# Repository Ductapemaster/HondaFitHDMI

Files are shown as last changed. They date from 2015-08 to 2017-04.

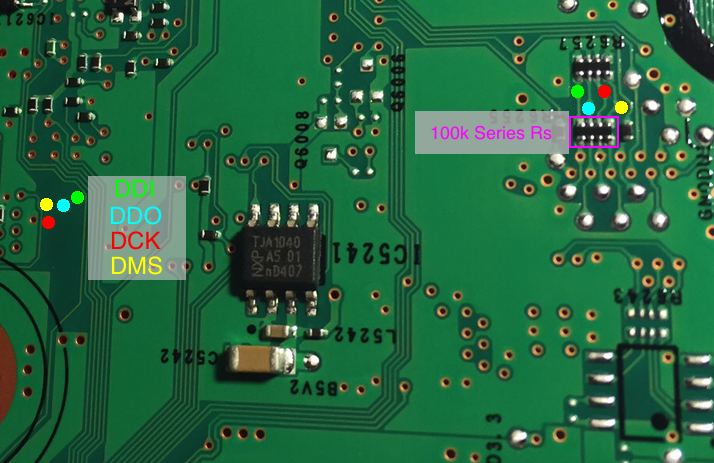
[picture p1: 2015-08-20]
wiki/hu_internals/annotated/v850_debug_signals.png

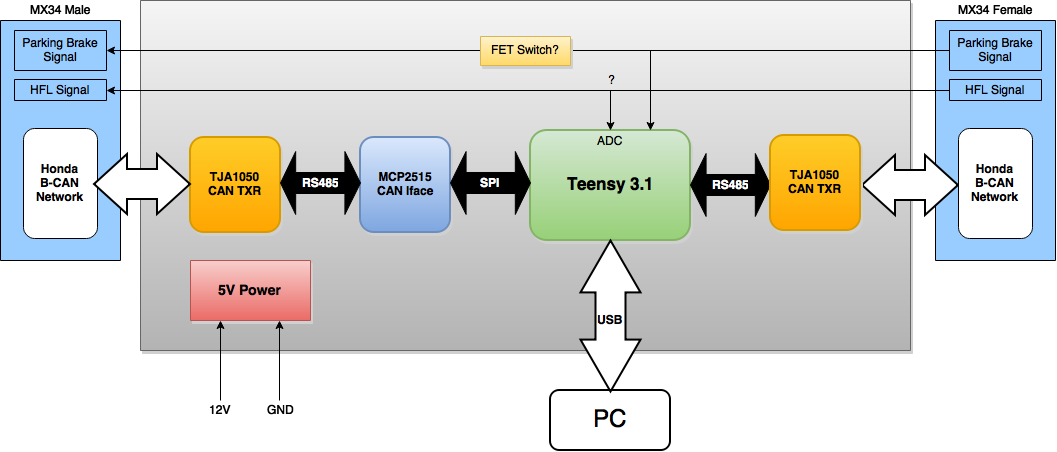
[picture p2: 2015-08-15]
wiki/images/block_diagram.png

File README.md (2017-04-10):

# HondaFitHDMI
Various efforts into hacking the 2015 Honda Fit head unit to allow HDMI input and disable other lockouts while driving

A demonstration of the prototype hardware can be found here: http://youtu.be/ffWo1LNsV7A

Please see the Wiki for the most updated information!

## Contents
**./can_analysis**: Captured data from CAN bus.  Analysis spreadsheet showing various IDs and their functions

**./proof_of_concept**: Files relating to the proof of concept hardware and software

**./teensy**: Firmware and related information for teensy-based prototype hardware

**./wiki**: Wiki content

# Git-iquette
Please forgive my tresspasses on the typical Git workflow.  This is my first solo git-tracked project and I'm learning as I go along!

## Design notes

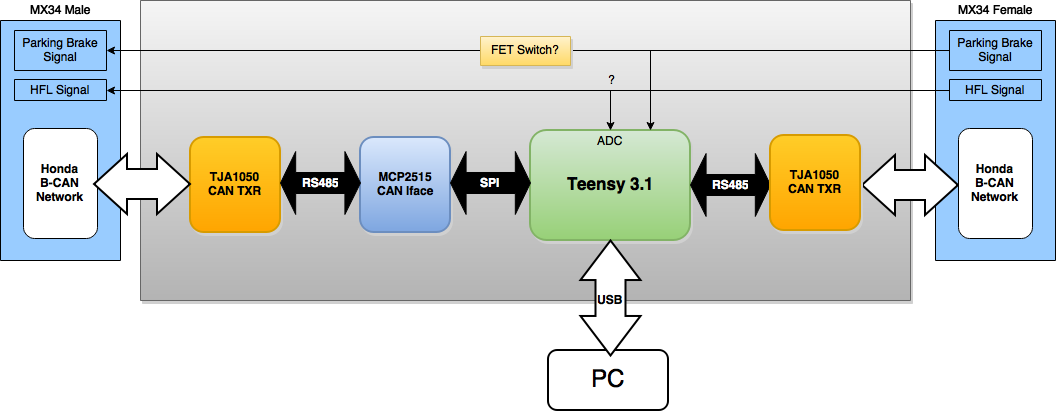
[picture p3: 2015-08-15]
wiki/images/proto_block_diagram.png

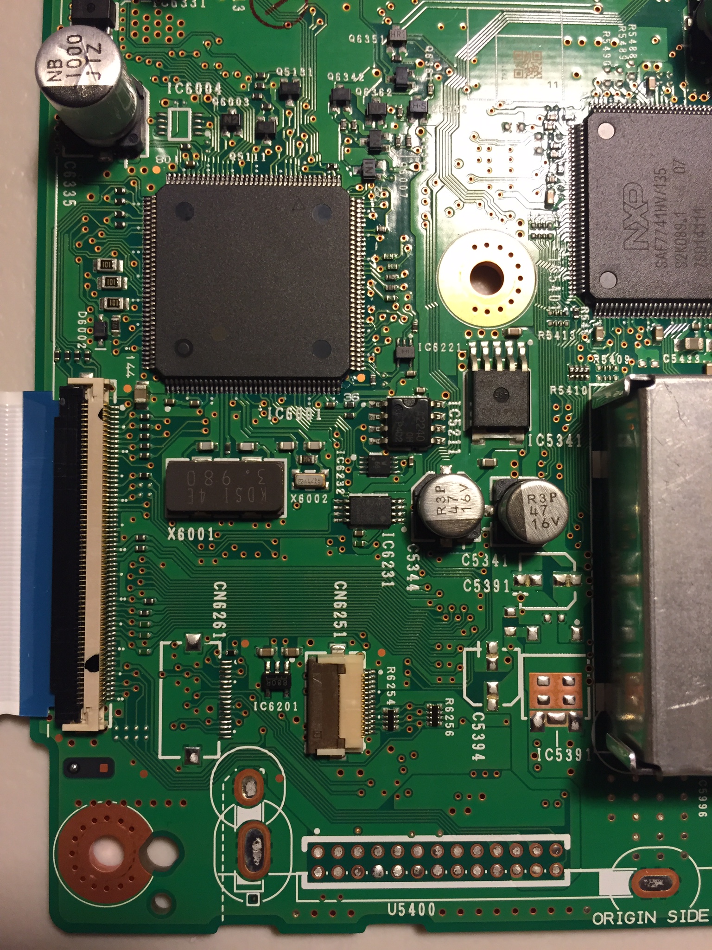
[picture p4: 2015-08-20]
wiki/hu_internals/original/pcb_audio_v850detail.JPG

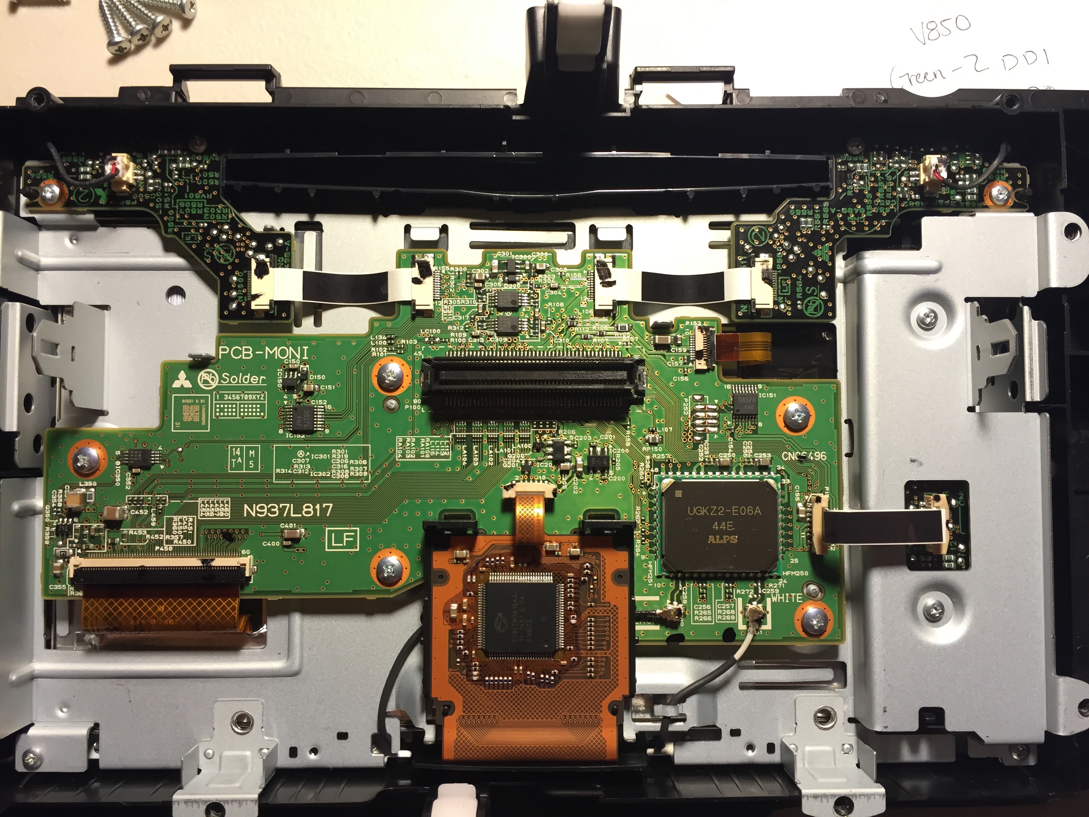
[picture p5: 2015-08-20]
wiki/hu_internals/original/pcb_display_bottom.jpg

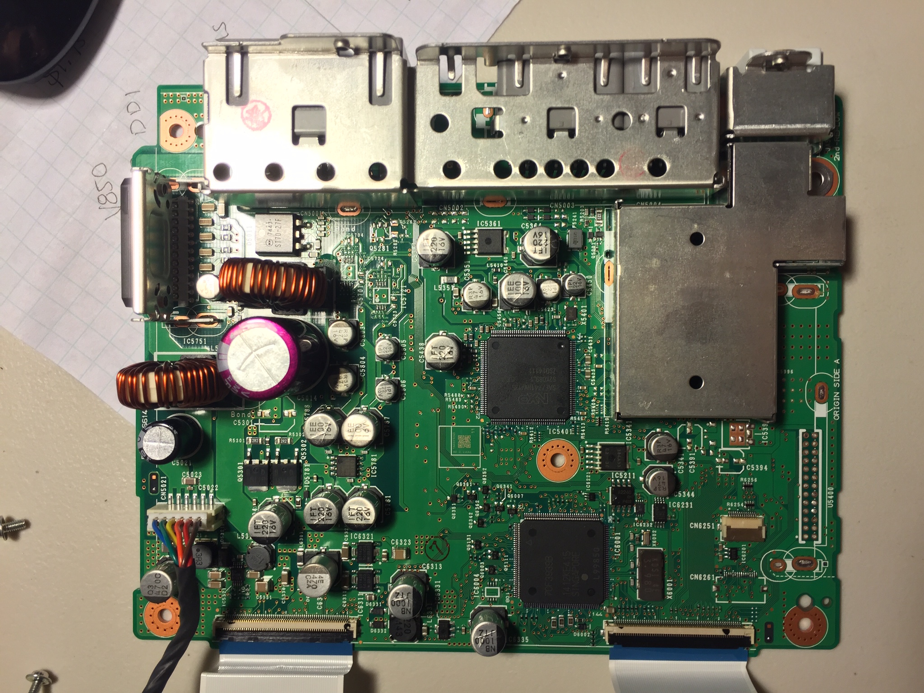
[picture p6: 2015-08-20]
wiki/hu_internals/original/pcb_audio_top.JPG

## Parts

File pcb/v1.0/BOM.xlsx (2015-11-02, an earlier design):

Part | Value | Device | Package | Description | MF | MPN | Digikey
C1 |  | C-EUC0603 | C0603 | CAPACITOR, European symbol |  |  | 478-6211-2-ND
C2 |  | C-EUC0603 | C0603 | CAPACITOR, European symbol |  |  | 478-6211-2-ND
C3 | 100n | C-EUC0603 | C0603 | CAPACITOR, European symbol |  |  | 311-1088-1-ND
D1 |  | LEDCHIP-LED0805 | CHIP-LED0805 | LED |  |  | 160-1423-1-ND
D2 |  | LEDCHIP-LED0805 | CHIP-LED0805 | LED |  |  | 160-1423-1-ND
Q1 | 10MHz | CRYSTALHC49S | HC49/S | CRYSTAL |  |  | 887-2008-ND
R1 | 120R | R-US_R0805 | R0805 | RESISTOR, American symbol |  |  | 311-120ARCT-ND
R2 | 120R | R-US_R0805 | R0805 | RESISTOR, American symbol |  |  | 311-120ARCT-ND
R3 | 120R | R-US_R0805 | R0805 | RESISTOR, American symbol |  |  | 311-120ARCT-ND
R4 | 120R | R-US_R0805 | R0805 | RESISTOR, American symbol |  |  | 311-120ARCT-ND
U1 | TEENSY_3.1_BASIC | TEENSY_3.1_BASIC | TEENSY_3.1_BASIC | Footprint for Teensy 3.1 board using all pin connections on the outer perimeter |  |  | 929974E-01-14-ND
U2 | MCP2515TSOP | MCP2515TSOP | TSSOP20 | MCP2515 Standalone CAN-Controller |  |  | MCP2515T-I/STCT-ND
U3 | TJA1050 | TJA1050 | SO08 | High speed CAN transceiver |  |  | 568-10292-1-ND
U4 | TJA1050 | TJA1050 | SO08 | High speed CAN transceiver |  |  | 568-10292-1-ND
X1 | CON_10X2F_JAE_MX34020NF1 | CON_10X2F_JAE_MX34020NF1 | CON_10X2_JAE_MX34020NF1 | JAE MX34 Series Connector, 10x2 Rows

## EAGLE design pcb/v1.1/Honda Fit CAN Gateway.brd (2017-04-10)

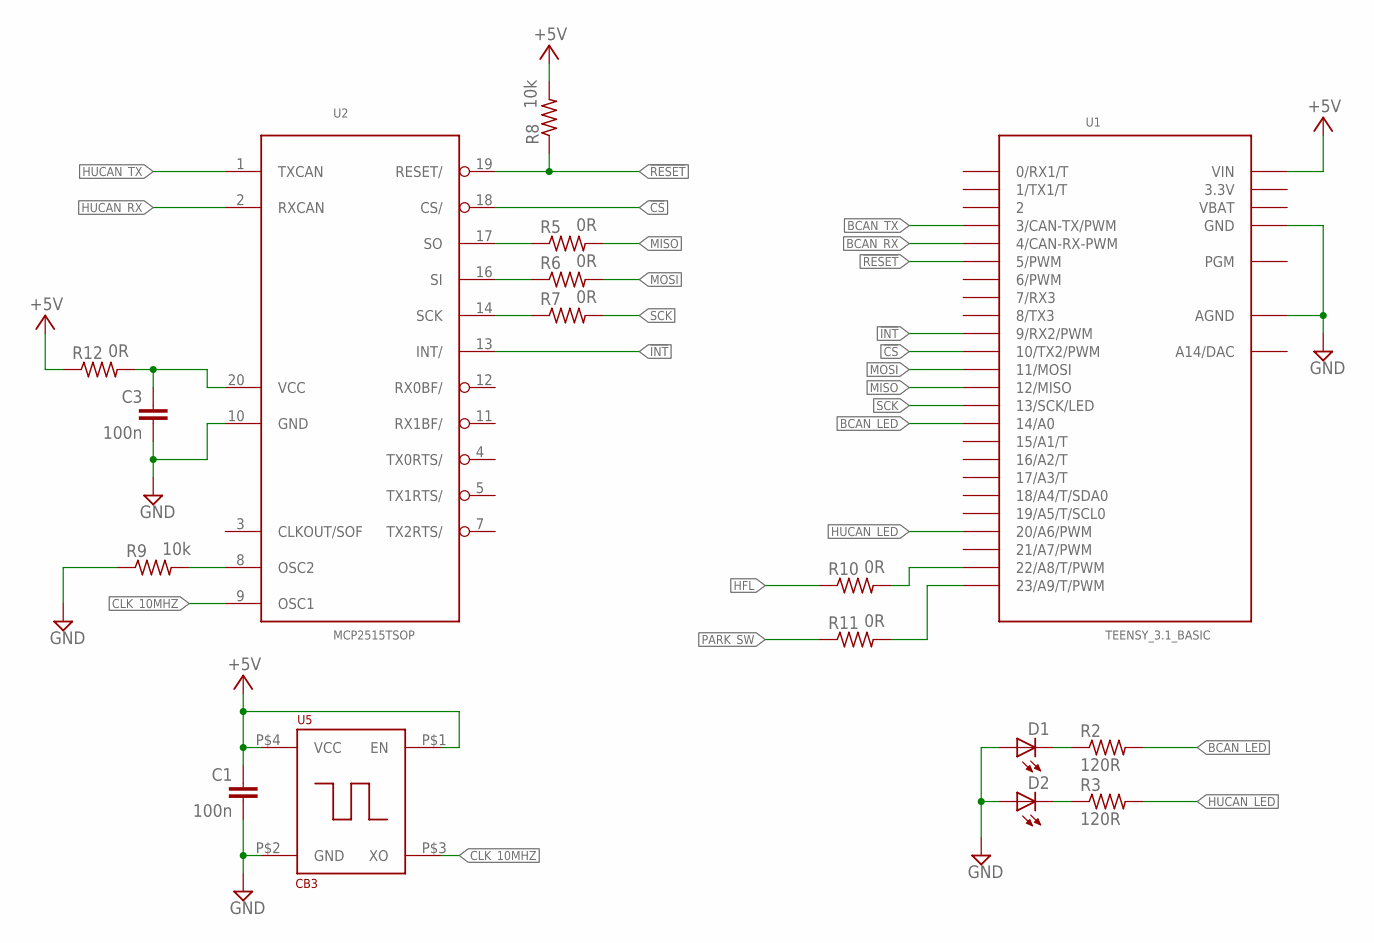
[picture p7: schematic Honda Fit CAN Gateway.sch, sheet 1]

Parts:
C1, C3: 100n; C0603
D1, D2: LEDCHIP-LED0805; CHIP-LED0805
R2, R3: 120R; R0805
R5, R6, R7, R10, R11, R12: 0R; R0805
R8, R9: 10k; R0805
U1: TEENSY_3.1_BASIC
U2: MCP2515TSOP; TSSOP20
U5: CB3; 4-SMD

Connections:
3.3V: U1.3.3V, U1.3.3V1 (3.3V)
!CS: U1.10 (10/TX2/PWM), U2.18 (CS/)
!INT: U1.9 (9/RX2/PWM), U2.13 (INT/)
!RESET: R8.1, U1.5 (5/PWM), U2.19 (RESET/)
+5V: C1.1, R8.2, R12.1, U1.VIN, U5.P$1 (EN), U5.P$4 (VCC); also elsewhere on the board
BCAN_LED: R2.2, U1.14/A0
BCAN_RX: U1.4 (4/CAN-RX-PWM); also elsewhere on the board
BCAN_TX: U1.3 (3/CAN-TX/PWM); also elsewhere on the board
CLK_10MHZ: U2.9 (OSC1), U5.P$3 (XO)
GND: C1.2, C3.2, D1.A, D2.A, R9.1, U1.AGND, U1.GND, U1.GND1 (GND), U2.10 (GND), U5.P$2 (GND); also elsewhere on the board
HFL: R10.1; also elsewhere on the board
HUCAN_LED: R3.2, U1.20/A6 (20/A6/PWM)
HUCAN_RX: U2.2 (RXCAN); also elsewhere on the board
HUCAN_TX: U2.1 (TXCAN); also elsewhere on the board
MISO: R5.2, U1.12 (12/MISO)
MOSI: R6.2, U1.11 (11/MOSI)
unnamed: R9.2, U2.8 (OSC2)
unnamed: R10.2, U1.22/A8 (22/A8/T/PWM)
unnamed: R11.2, U1.23/A9 (23/A9/T/PWM)
unnamed: D1.C, R2.1
unnamed: D2.C, R3.1
unnamed: R5.1, U2.17 (SO)
unnamed: R6.1, U2.16 (SI)
unnamed: R7.1, U2.14 (SCK)
unnamed: C3.1, R12.2, U2.20 (VCC)
PARK_SW: R11.1; also elsewhere on the board
SCK: R7.2, U1.13 (13/SCK/LED)
VBAT: U1.VBAT

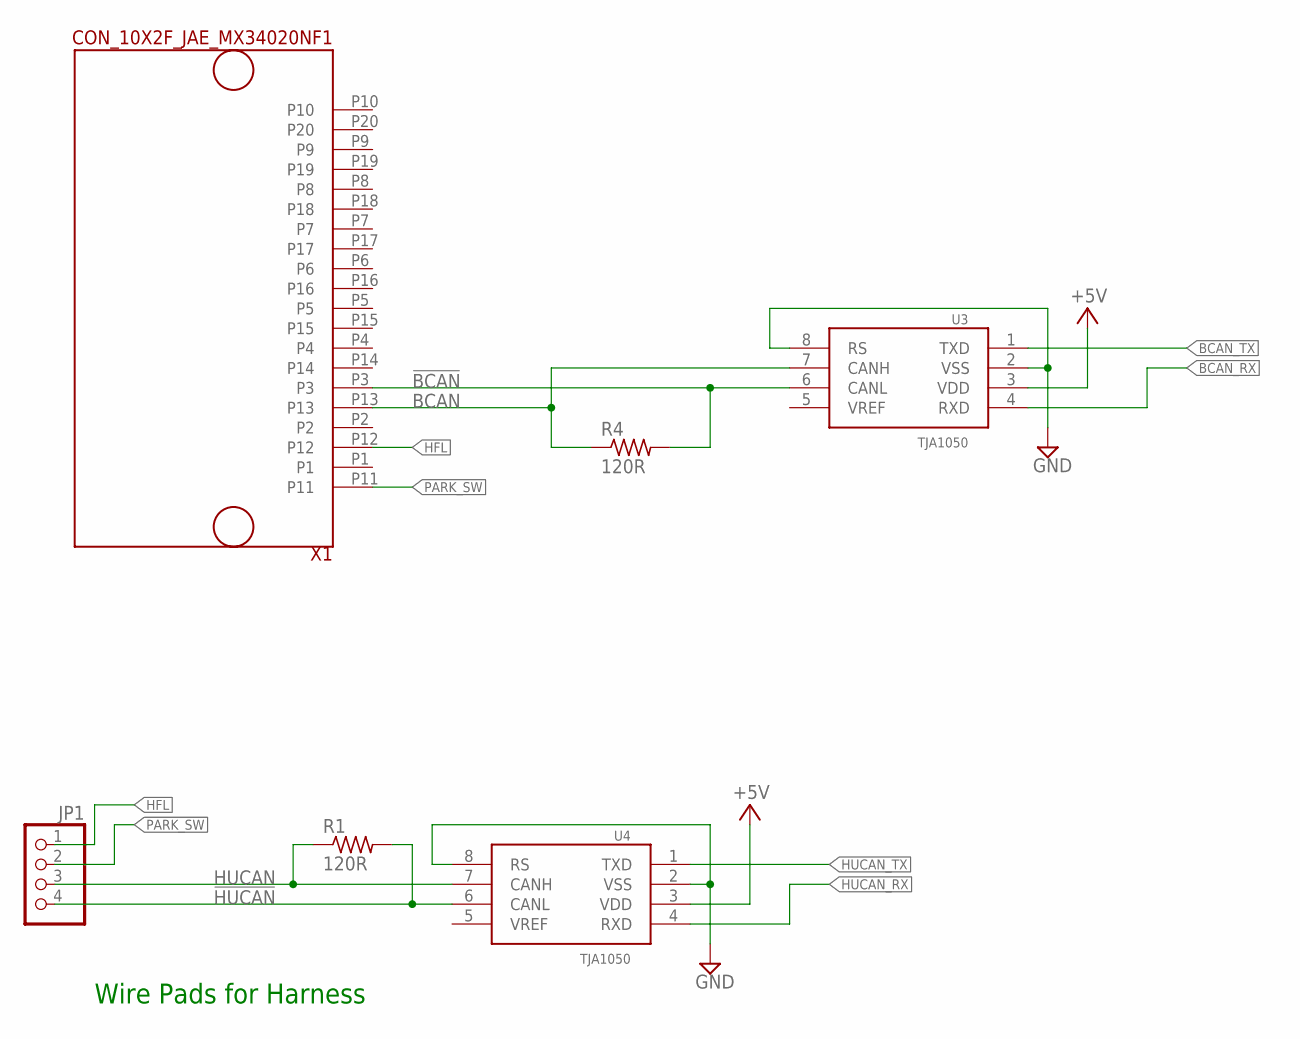
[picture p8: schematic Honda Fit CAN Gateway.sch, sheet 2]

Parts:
JP1: PINHD-1X4; 1X04
R1, R4: 120R; R0805
U3, U4: TJA1050; SO08
X1: CON_10X2F_JAE_MX34020NF1; CON_10X2_JAE_MX34020NF1

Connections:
!BCAN: R4.2, U3.6 (CANL), X1.P3
!HUCAN: JP1.4, R1.2, U4.6 (CANL)
+5V: U3.3 (VDD), U4.3 (VDD); also elsewhere on the board
BCAN: R4.1, U3.7 (CANH), X1.P13
BCAN_RX: U3.4 (RXD); also elsewhere on the board
BCAN_TX: U3.1 (TXD); also elsewhere on the board
GND: U3.2 (VSS), U3.8 (RS), U4.2 (VSS), U4.8 (RS); also elsewhere on the board
HFL: JP1.1, X1.P12; also elsewhere on the board
HUCAN: JP1.3, R1.1, U4.7 (CANH)
HUCAN_RX: U4.4 (RXD); also elsewhere on the board
HUCAN_TX: U4.1 (TXD); also elsewhere on the board
PARK_SW: JP1.2, X1.P11; also elsewhere on the board

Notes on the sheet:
Wire Pads for Harness

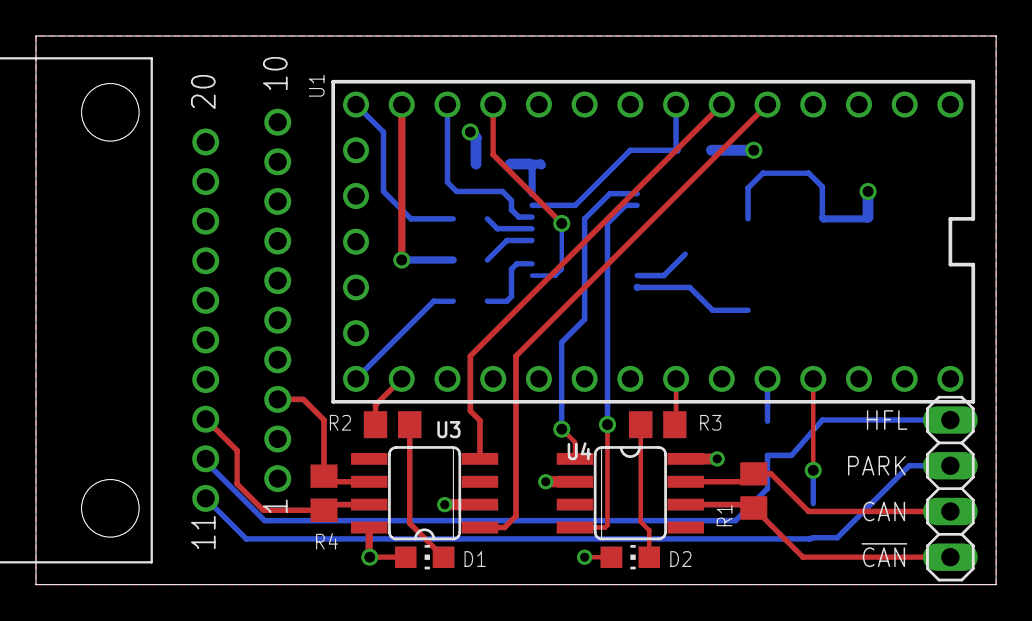
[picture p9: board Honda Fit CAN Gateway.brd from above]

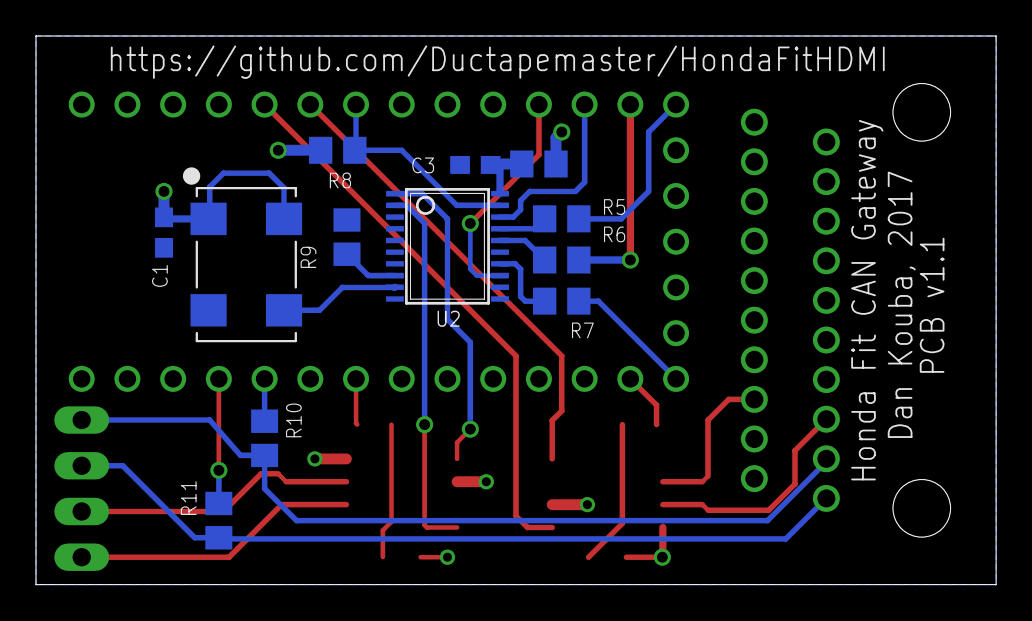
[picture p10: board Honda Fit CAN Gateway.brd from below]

Board: 2 copper layers, 53.3 x 30.5 mm, 23 parts (12 on the bottom side), 31 nets.

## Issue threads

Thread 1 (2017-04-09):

X1 (Female JAE connector) holes are not correctly placed

Ductapemaster, 2017-04-09:
The screw holes in the footprint for X1 are slightly off

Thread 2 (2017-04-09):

SCK rise time too fast for MCP2515

Ductapemaster, 2017-04-09:
# Issue Description
The Teensy was not able to communicate with the MCP2515 when assembled on either the V1.0 and 1.1 PCB.  If wires were ran from the PCB connector for the Teensy to the Teensy (separating it from the board), the serial lines worked again.

# Diagnosis
Lands for series components on the serial lines were placed on V1.1 PCB, and it was determined that a series inductor on the clock line enabled communication to resume.

The rise time of the Teensy's serial clock was measured to be 3.3ns.  The series inductor reduced the edge rate of the clock and resulted in a rise time of 8.1ns.  The inductor used was a LCB1206-601 (Z=600 ohms @ 100Mhz).

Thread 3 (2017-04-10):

Pull power from head unit if possible

Ductapemaster, 2017-04-10:
A Thai company has a device that performs very similarly to my design, and it does not require external power.  Instead, it appears to have an extra wire or two going to the head unit connector, presumably carrying power.

[Video link](https://www.youtube.com/watch?v=RaONZLDWY0s)

Need to pull apart head unit again, and/or probe with a multimeter to find some power on the head unit connector.

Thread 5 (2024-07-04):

Comments

Noitarud, 2024-07-04:
I have a LSP2GTS head unit I was thinking of modifying, I noticed it has a TW8816 for controlling the LCD, so I could lock out the original MCU altogether by using my own simple MCU or the one built into the TW8816 (their AU1340 MCU is on the digital input. TW has Svideo,RGB,component,composite options). It also has a CY8C1334, its the same mf as your touch screen IC, it is a product by Cypress, it is a microcontroller with the features they need to make the touch work, so there would be minimum codespace used in it (so I could have used that one too). Your LCD controller seems embedded in the MCU.

I only visited your project because I thought to use the DSP, yours is the same, they won't give me the I2C commands unless I buy an IC. The TW chip, someone put their "Confidential" information online (not the MCU part) so I can convert mine to a monitor (I can also make an array of displays). I will probably have to spy on the I2C commands.

I am guessing you are proposing the RPi because you are familiar, did you consider more primitive MCUs (microchip/amtel/8052 clones)? You may be able to get that cypress to work for what you want (but I am dubious about doing any soldering on plastic!) its programming inputs might be on the end of the cable, but you would still need to solder to unused IOs, and work around the existing code.

Comments so far. I have been writing MCU code so not much progress, learning to organise.
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

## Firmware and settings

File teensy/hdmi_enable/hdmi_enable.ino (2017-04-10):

// -------------------------------------------------------------
// hdmi_enable for Teensy 3.1
// by ductapemaster
//
// This code successfully disables HDMI lockout and lockout of specific features at speed.
//
// Two frames are edited before passing through:
// 1. Gear shifter value set permanently to "park"
// 2. Vehicle speed value set permanently to '0'
//
// Only passes CAN data from car to head unit.  Head unit output frames are currently unhandled.

#include <FlexCAN.h>
#include <teensy_mcp_can.h>
#include<SPI.h>
#include <spi4teensy3.h>

//#define debug

// LED for receive indication.  Can't use onboard one because it shares the SPI SCLK pin
const int bcan_led  = 14;
const int hucan_led = 20;
const int park      = 22;
const int hfl       = 23;
const int rst       = 5;

//FlexCAN
FlexCAN CANIn(125000);
static CAN_message_t rxmsg;

//MCP2515 CAN
//Interrupt is D2, from schematic
//Default SPI Pins on Teensy:
// CS:        10
// DOUT/MOSI: 11
// DIN/MISO   12
// SCLK       13 (also the LED!)

//MCP library requires CS pin as argument.  Use default.
// this actually doesn't matter since we are overwriting the calls to the Arduino SPI lib with calls to spi4teensy3
const int csPin = 10;
MCP_CAN CANOut(csPin);
bool filter_out = false;

// -------------------------------------------------------------
static void printCanFrame(CAN_message_t f)
{
      Serial.print(millis());
      Serial.print("ms");
      Serial.print("\t0x");
      Serial.print(f.id, HEX);
      Serial.print("\t[");
      Serial.print(f.len);
      Serial.print("]\t");
      for (int i = 0; i < f.len; i++) 
      {
        Serial.print(f.buf[i], HEX);
        Serial.print("  ");
      }
      Serial.write('\r');
      Serial.write('\n');
}

// -------------------------------------------------------------
void setup(void)
{

  CANIn.begin();
  Serial.begin(115200);

  // MCP2515 Reset Setup
  pinMode(rst, OUTPUT);
  digitalWrite(rst, 0);

  // LED Setup
  pinMode(bcan_led,  OUTPUT);
  pinMode(hucan_led, OUTPUT);
  digitalWrite(bcan_led,  0);
  digitalWrite(hucan_led, 0);

  // Inputs
  pinMode(park, INPUT);
  pinMode(hfl,  INPUT);

  delay(1000);

  // Bring MCP2515 out of reset
  digitalWrite(rst, 1);
  
  // F() stores string in flash rather than RAM
  Serial.println(F("HDMI Enable Test"));

  Serial.print(F("Initializing MCP2515 interface..."));

  // Attempt to initialize module
  while (CAN_OK != CANOut.begin(CAN_125KBPS))
  {
    // Loops forever - probably should implement some sort of timeout.  Watchdog?
    Serial.print(".");
    delay(300);
  }
  
  Serial.println("success\r\n");

  digitalWrite(bcan_led, 1);
  digitalWrite(hucan_led, 1);

}


// -------------------------------------------------------------
void loop(void)
{
    // Poll CAN buffer for new data
    while ( CANIn.read(rxmsg) ) {

      filter_out = false;

      // Toggle our LED to show bus activity
      digitalWrite(bcan_led, 1);
      
      #ifdef debug
      printCanFrame(rxmsg);
      #endif

      // Modify multiple frames based on conditional data
      switch (rxmsg.id) {

        // Gear Shifter/Parking Brake Position
        case 0x12F85150:
          
          Serial.println("changing gear to park!");
          Serial.print("before: ");
          printCanFrame(rxmsg);
          rxmsg.buf[0] = 0x40;
          rxmsg.buf[1] = 0x03;
          Serial.print("after: ");
          printCanFrame(rxmsg);
          break;

        // Vehicle Speed/Engine RPM - verified!
        case 0x12F85050:
          Serial.println("changing speed to 0!!");
          Serial.print("before: ");
          printCanFrame(rxmsg);
          rxmsg.buf[0] = 0x00;
          Serial.print("after: ");
          printCanFrame(rxmsg);
          break;        
          
        default:
          break;
        
      }
      
      digitalWrite(bcan_led, 0);

      // Write buffered data to second CAN bus
      // ID, CAN Mode: 1=extended, buffer length, buffer     
      // There's got to be a better way to do this - can we use the canframe object?
      //if (!filter_out)
      //{
        digitalWrite(hucan_led, 1);
        CANOut.sendMsgBuf(rxmsg.id, 1, rxmsg.len, rxmsg.buf);
        digitalWrite(hucan_led, 0);
      //}
      
    }

    

}

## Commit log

2015-08-04 Playing around with the parser. Prints out some debug info now, and also a list of unique addresses and how many frames occured with that specific address
2015-08-05 Various functions added to parser. Creates CSV for input file and outputs interesting addresses. CSV files committed. Forked c library for reading CAN data live from interface for future monitoring p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
    [candump-2015-08-04_011211-CAR_ON_IDLE.csv, candump-2015-08-04_011542_PARK_REVERSE_3X.csv, candump-2015-08-04_011731_DRIVERS_DOOR_OPEN_CLOSE_3X.csv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]
2015-08-05 adding capture of shifter ID only from today
    [candump-2015-08-05_064025.csv]
2015-08-09 Added script that sends out CAN frame repeatedly representing the car being in park. This partially triggers the desired behavior of the head unit - the correct video enabled flags are set in the dia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
2015-08-15 Adding directory for wiki content. Adding prototype block diagram
2015-08-22 Removing canhack subproject. Adding teensy tests for prototype hardware.
2015-08-22 Adding working prototype code. Successfully passes through CAN data to head unit and modifying gear shifter frame to be in park, which enables HDMI input all the time.
2015-08-27 Cleaning things up and adding CAN bus analysis spreadsheet
    [candump-2015-08-04_011211-CAR_ON_IDLE.csv, candump-2015-08-04_011542_PARK_REVERSE_3X.csv, candump-2015-08-04_011731_DRIVERS_DOOR_OPEN_CLOSE_3X.csv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]
2015-08-27 Readability fixes in CAN bus analysis spreadsheet
2015-08-28 Consolidating teensy firmware files. Adding working version of code for enabling HDMI and other locked out features while driving
2015-11-02 Adding schematic and pcb files. v1.0 was sent to fab
    [BOM.xlsx, Honda Fit CAN Gateway.brd, Honda Fit CAN Gateway.sch]
2015-11-02 Creating v1.1 schematic and pcb files from v1.0
    [Honda Fit CAN Gateway.brd, Honda Fit CAN Gateway.sch]
2017-01-24 Add series resistors on MCP2515 SPI lines
    Lands can be used for any 0603 part
    [Honda Fit CAN Gateway.sch]
2017-01-24 Add Eagle library with tiny Kemet relay
    For future versions
2017-01-24 Add datasheet for 1.2A buck converter
    For future designs
2017-01-24 Add 10k pullup for reset
    Datasheet recommended
    [Honda Fit CAN Gateway.sch]
2017-01-24 Replace xtal with oscillator. Connect reset to Teensy
    [Honda Fit CAN Gateway.sch]
2017-01-24 Replace discrete pads for output with pin header footprint
    Pads were too large on rev 1, and square orientation was not ideal
    [Honda Fit CAN Gateway.sch]
2017-01-26 Major additions and changes
    Added jumper resistors between Park and HFL nets and the Teensy to allow decoupling. Added land for inductor on MCP2515 +5V rail (805 resistor package). Reordered some pins to make layout easier.
    [Honda Fit CAN Gateway.sch]
2017-01-26 V1.1 PCB preliminary commit
    Need to review. All signals routed - no rats.
    [Honda Fit CAN Gateway.brd]
2017-01-26 Change resistor value
    Change resistor land used for MCP2515 supply inductor to be 0 ohms for clarity
    [Honda Fit CAN Gateway.brd, Honda Fit CAN Gateway.sch]
2017-01-31 Move silkscreen and a couple of traces
    [Honda Fit CAN Gateway.brd]
2017-01-31 Add datasheet for JAE MX34 connector
2017-04-10 Add newest teensy firmware files
